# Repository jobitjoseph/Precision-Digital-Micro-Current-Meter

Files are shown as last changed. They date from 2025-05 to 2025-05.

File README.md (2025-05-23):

# Precision-Digital-Micro-Current-Meter
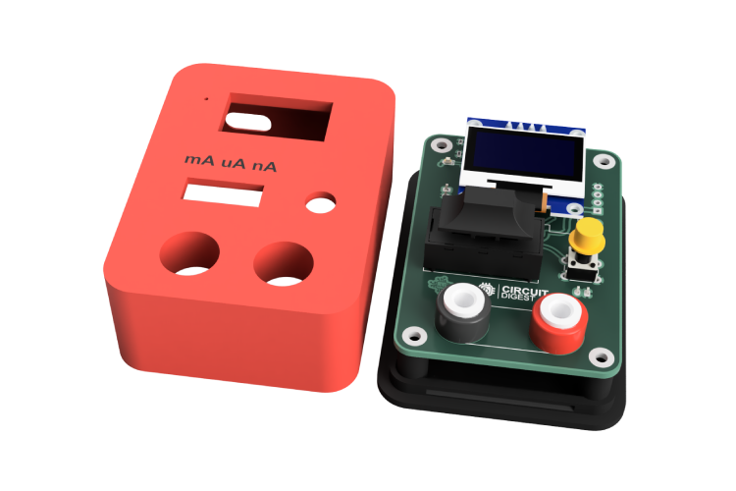
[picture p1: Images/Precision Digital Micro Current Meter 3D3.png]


Keeping track of extremely low current levels is often essential when developing or testing low-power devices, especially in the field of embedded systems and battery-operated electronics. This project presents a compact and reliable micro current meter that makes such measurements straightforward and accessible. It is built around an STM32 microcontroller and features an OLED display for real-time readouts. The analog front end is designed to detect small current flows accurately, converting them into voltage levels that the microcontroller can process with high resolution. Whether you're measuring sleep current in a sensor node or characterising a power-efficient circuit, the device offers a clear and immediate view of power consumption trends.

The meter is designed for ease of use on the workbench, with a focus on readability, stability, and portability. The OLED display provides a crisp output that remains visible under most lighting conditions, while the microcontroller handles signal processing and automatic range detection. Calibration routines ensure measurement consistency across various load conditions. With no need for external tools or complex setups, the device offers a plug-and-play experience for engineers, developers, or hobbyists working with ultra-low power electronics. Its practical design makes it a useful tool for anyone seeking to analyse power usage with precision and simplicity.

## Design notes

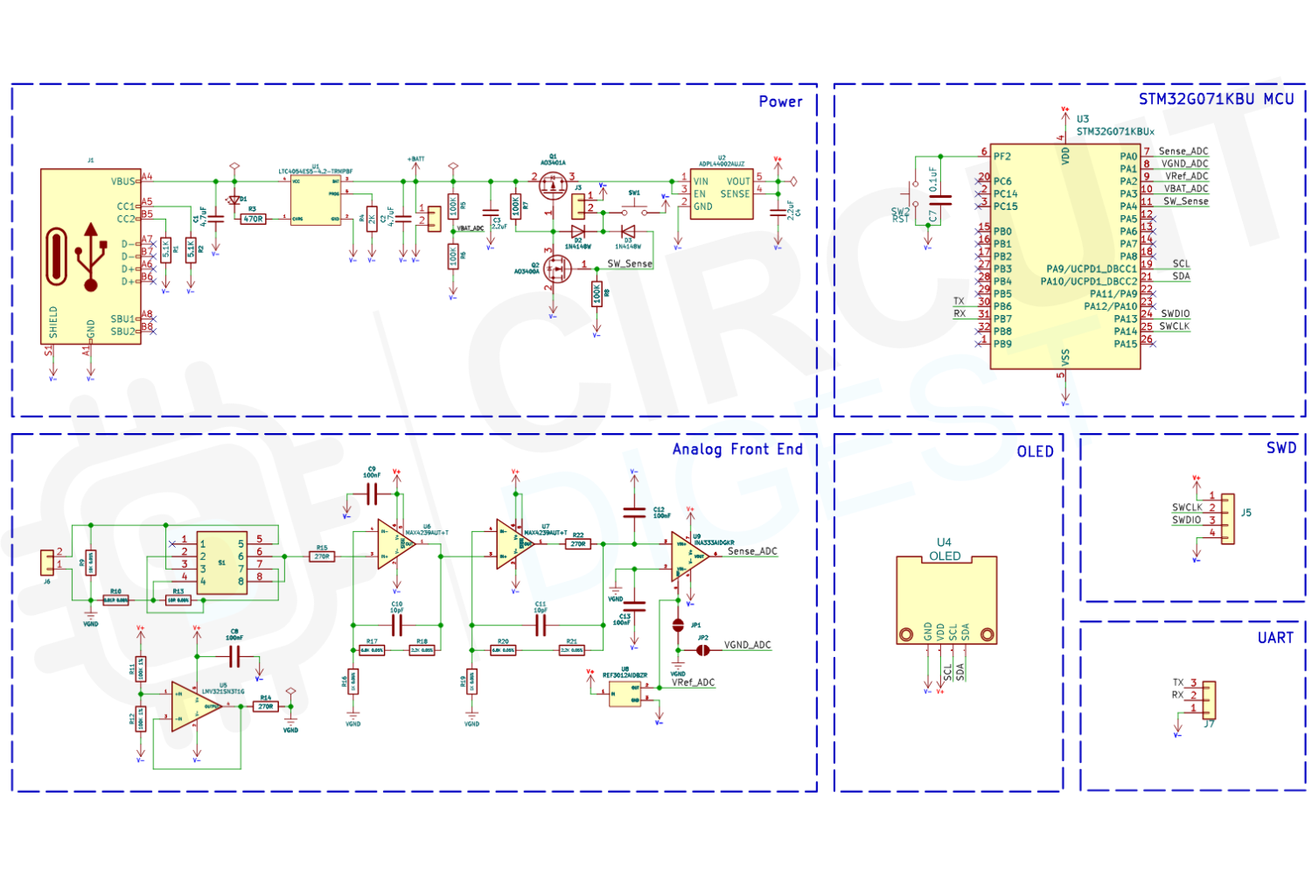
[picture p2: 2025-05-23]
Images/Precision Digital Micro Current Meter Schematics.png

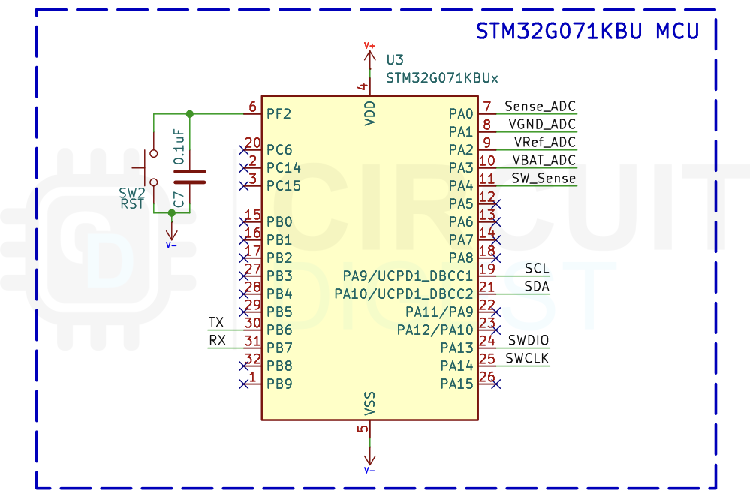
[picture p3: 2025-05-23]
Images/Precision Digital Micro Current Meter MCU.png

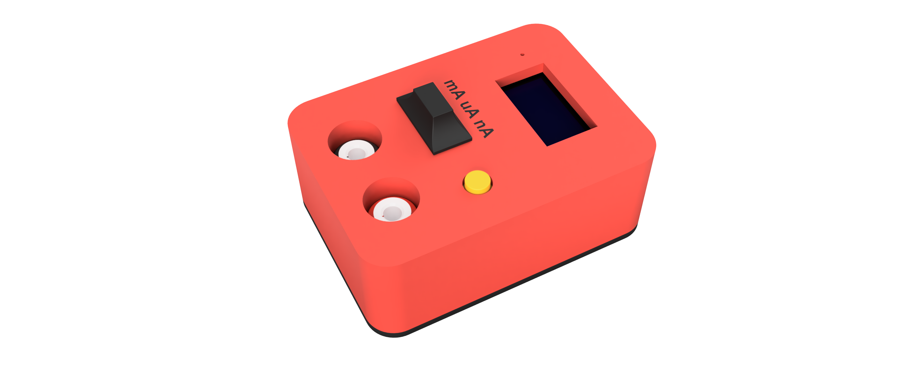
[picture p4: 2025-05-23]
Images/Og/Precision Digital Micro Current Meter 3D view.png

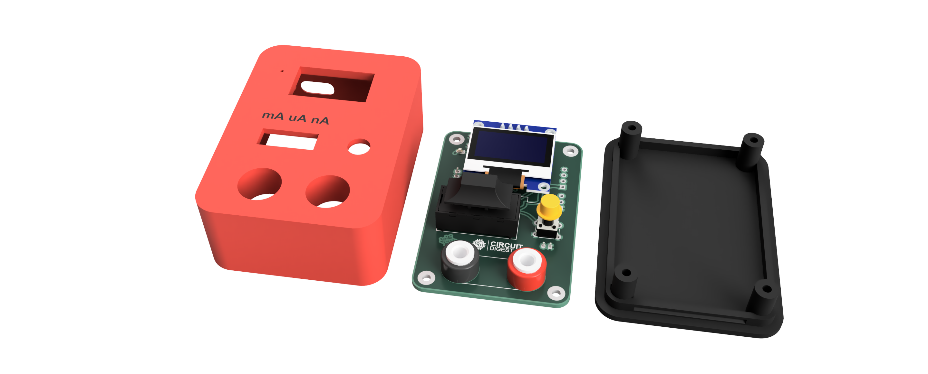
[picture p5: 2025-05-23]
Images/Og/Precision Digital Micro Current Meter 3D.png

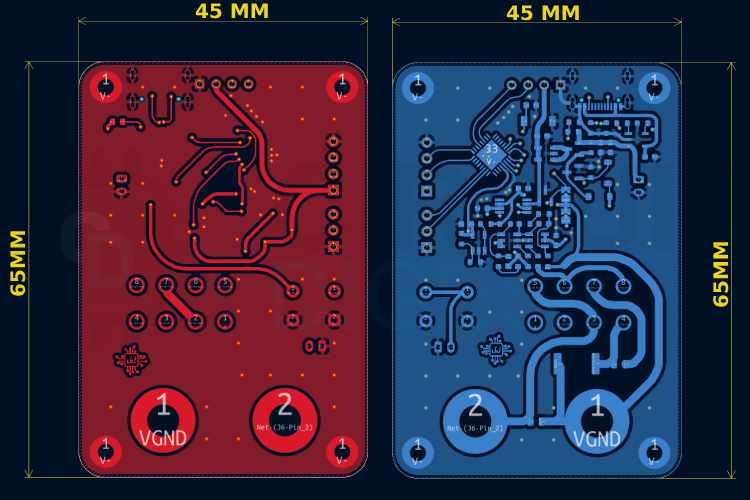
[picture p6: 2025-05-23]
Images/Precision Digital Micro Current Meter PCB Layers.png

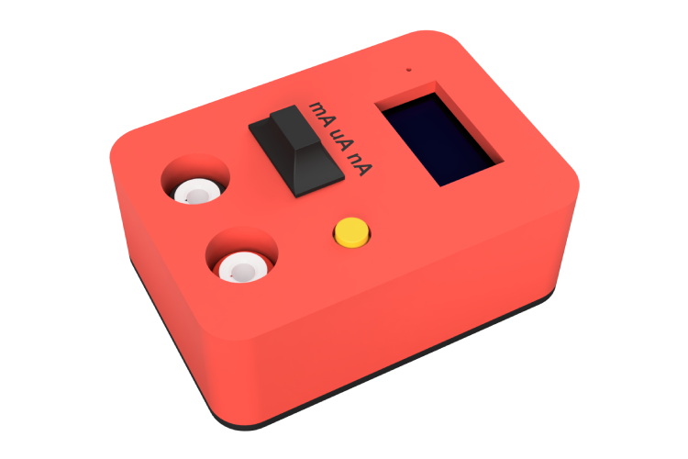
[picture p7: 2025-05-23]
Images/Precision Digital Micro Current Meter 3D1.png

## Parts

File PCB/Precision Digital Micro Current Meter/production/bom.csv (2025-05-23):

Designator | Footprint | Quantity | Value | LCSC Part #
C1, C2 | 0603 | 2 | 4.7uF
C10, C11 | 0603 | 2 | 10pF
C12, C13, C8, C9 | 0603 | 4 | 100nF
C3, C4 | 0603 | 2 | 2.2uF
C7 | 0603 | 1 | 0.1uF
D1 | 0603 | 1 | LED_Small
D2, D3 | D_SOD-123 | 2 | 1N4148W
J1 | USB_C_Receptacle_Palconn_UTC16-G | 1 | USB_C_Receptacle_USB2.0_16P
J2 | JST_PH_B2B-PH-K_1x02_P2.00mm_Vertical | 1 | B2B-PH-SM4-TB(LF)(SN)
J3 | JST_PH_B2B-PH-K_1x02_P2.00mm_Vertical | 1 | Conn_01x02
J4 | PinHeader_1x03_P2.54mm_Vertical | 1 | Conn_01x03
J5 | PinHeader_1x04_P2.54mm_Vertical | 1 | Conn_01x04
J6 | Banana_Jack_2Pin | 1 | Conn_01x02
JP1, JP2 | SolderJumper-2_P1.3mm_Open_TrianglePad1.0x1.5mm | 2 | SolderJumper_2_Open
Q1 | SOT-23 | 1 | AO3401A
Q2 | SOT-23 | 1 | AO3400A
R1, R2 | 0603 | 2 | 5.1K
R10 | 2512 | 1 | 0.01R 0.05%
R11, R12 | 0603 | 2 | 100K 1%
R13 | 0805 | 1 | 10R 0.05%
R14, R15, R22 | 0603 | 3 | 270R
R16, R19 | 0603 | 2 | 1K 0.05%
R17, R20 | 0603 | 2 | 6.8K 0.05%
R18, R21 | 0603 | 2 | 2.2K 0.05%
R3 | 0603 | 1 | 470R
R4 | 0603 | 1 | 2K
R5, R6, R7, R8 | 0603 | 4 | 100K
R9 | 0805 | 1 | 10K 0.05%
S1 | L203111MS02Q | 1 | L203011MS02Q
SW1 | SW_PUSH_6mm | 1 | SW_Push
SW2 | Tactile 3x4x2mm TS-A010 | 1 | RST
U1 | S_5_ADI | 1 | LTC4054ES5-4.2-TRMPBF
U2 | SOT95P280X100-5N | 1 | ADPL44002AUJZ
U3 | QFN-32-1EP_5x5mm_P0.5mm_EP3.45x3.45mm | 1 | STM32G071KBUx
U4 | MODULE_DM-OLED096-636 | 1 | OLED
U5 | SOT95P275X110-5N | 1 | LMV321SN3T1G
U6, U7 | SOT95P280X145-6N | 2 | MAX4239AUT+T
U8 | DBZ3 | 1 | REF3012AIDBZR
U9 | SOP65P490X110-8N | 1 | INA333AIDGKR

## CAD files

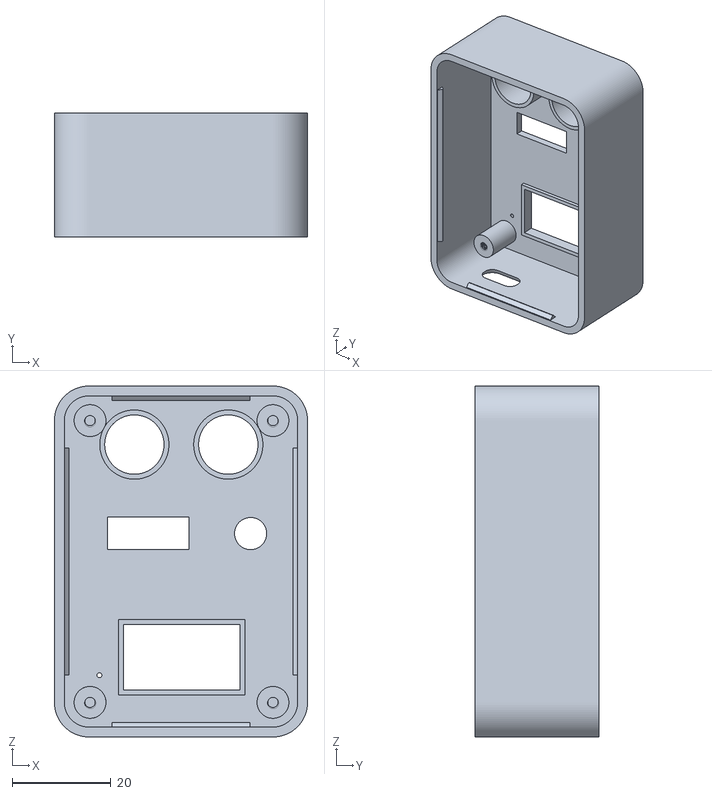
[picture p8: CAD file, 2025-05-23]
3D Files/Top_Case.stl
51.2 x 25.0 x 71.0

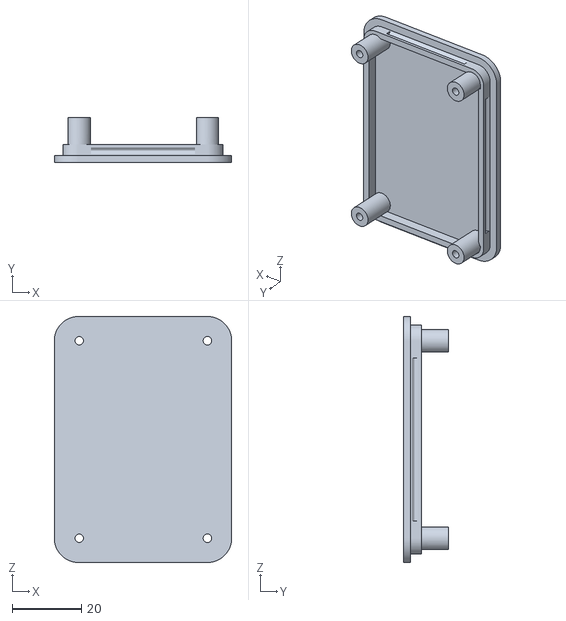
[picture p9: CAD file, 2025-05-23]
3D Files/Bottom_Case.stl
51.2 x 13.0 x 71.0

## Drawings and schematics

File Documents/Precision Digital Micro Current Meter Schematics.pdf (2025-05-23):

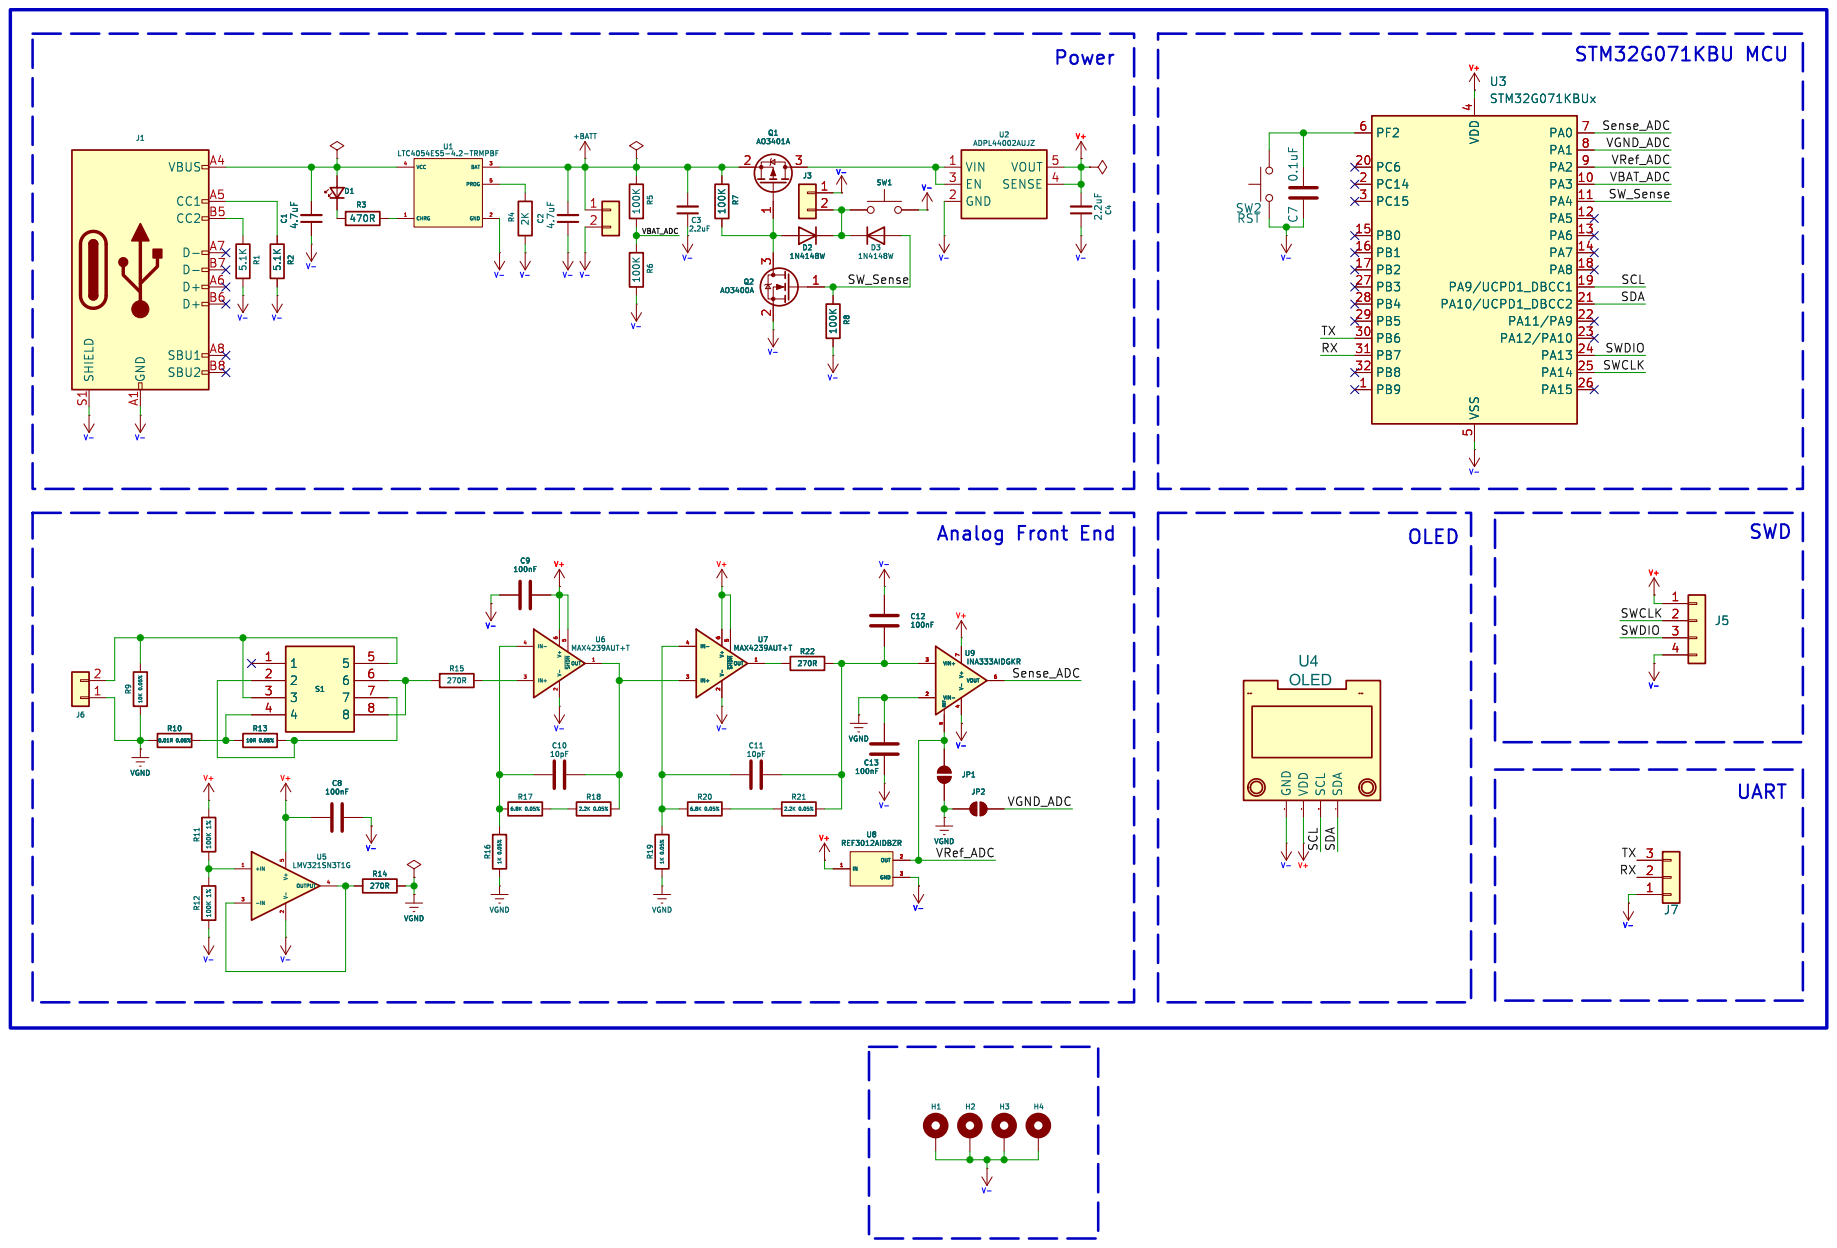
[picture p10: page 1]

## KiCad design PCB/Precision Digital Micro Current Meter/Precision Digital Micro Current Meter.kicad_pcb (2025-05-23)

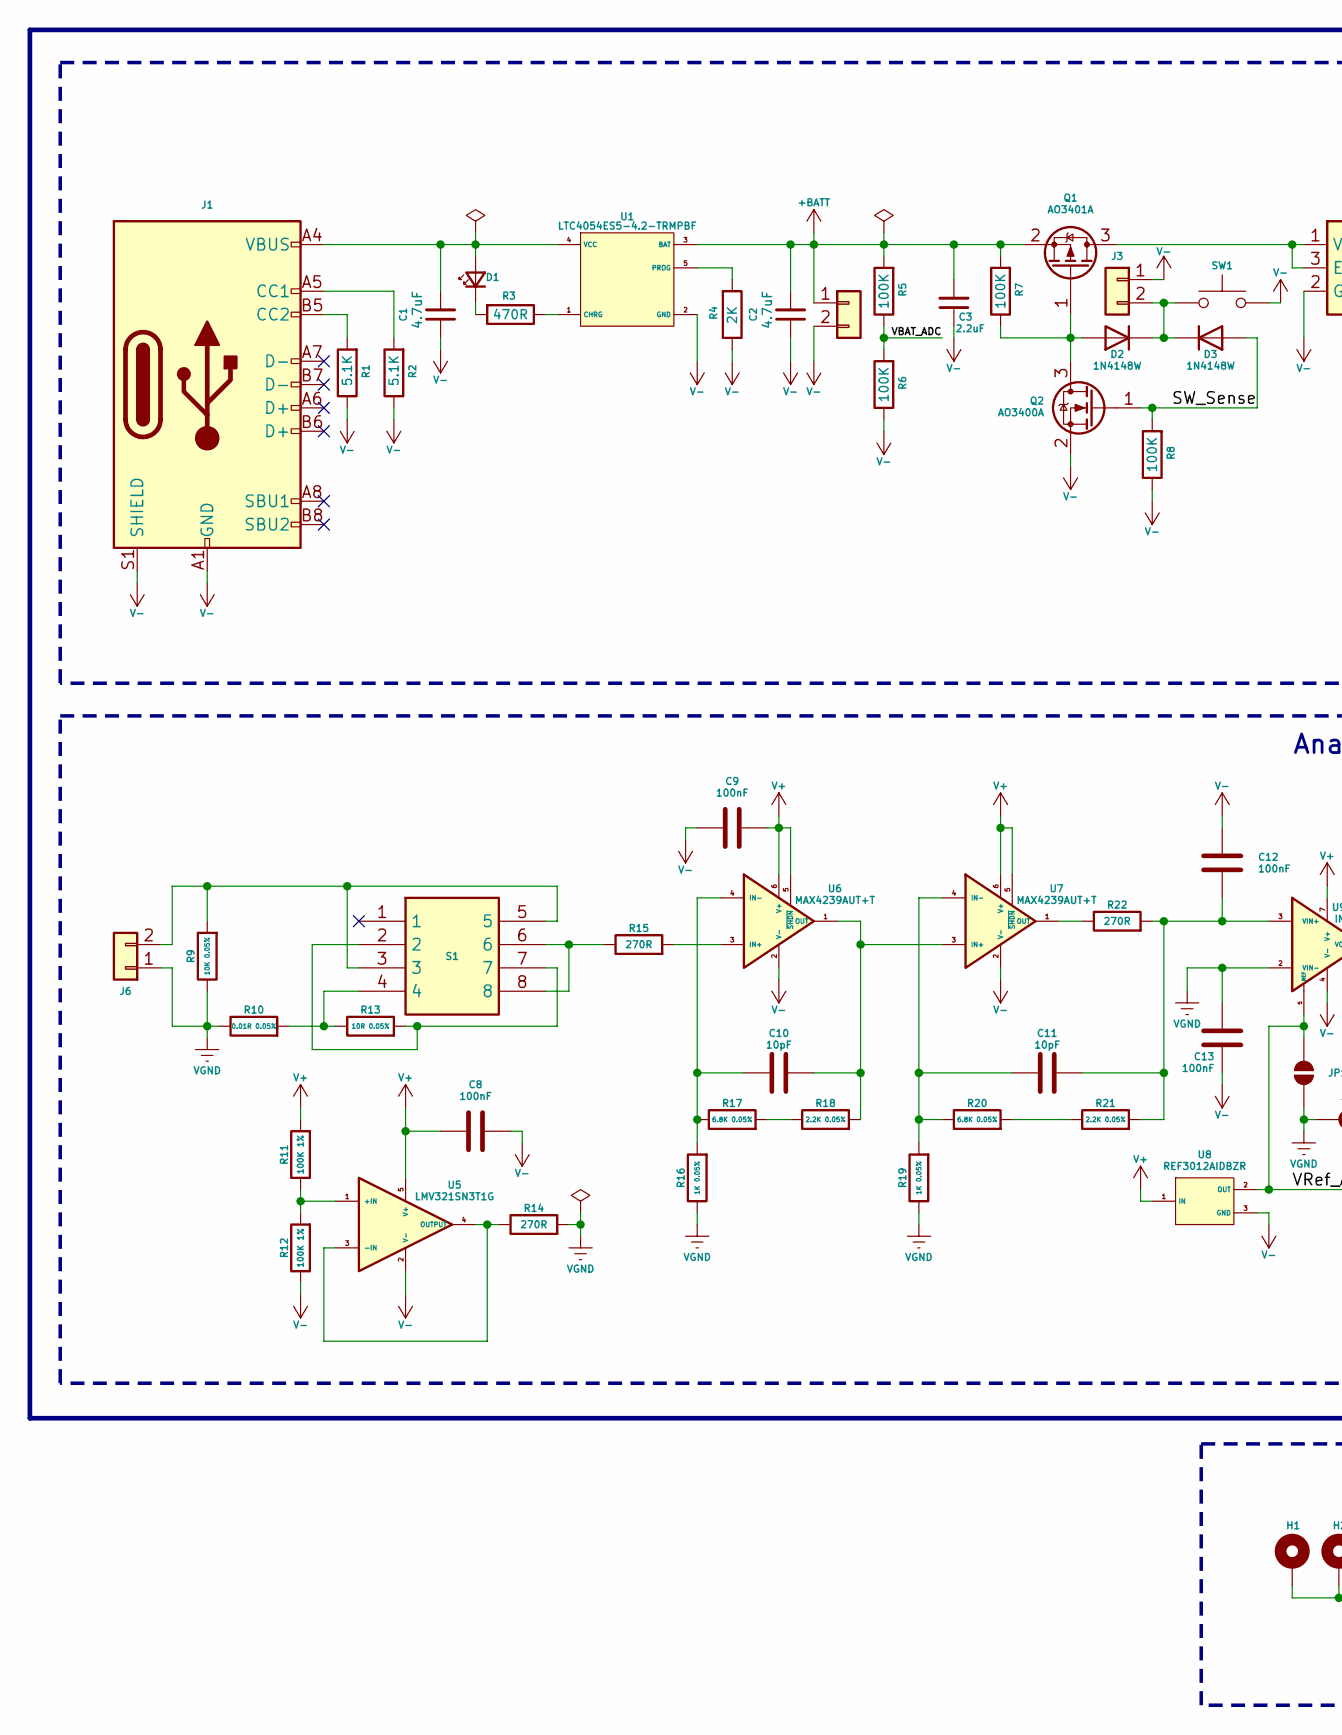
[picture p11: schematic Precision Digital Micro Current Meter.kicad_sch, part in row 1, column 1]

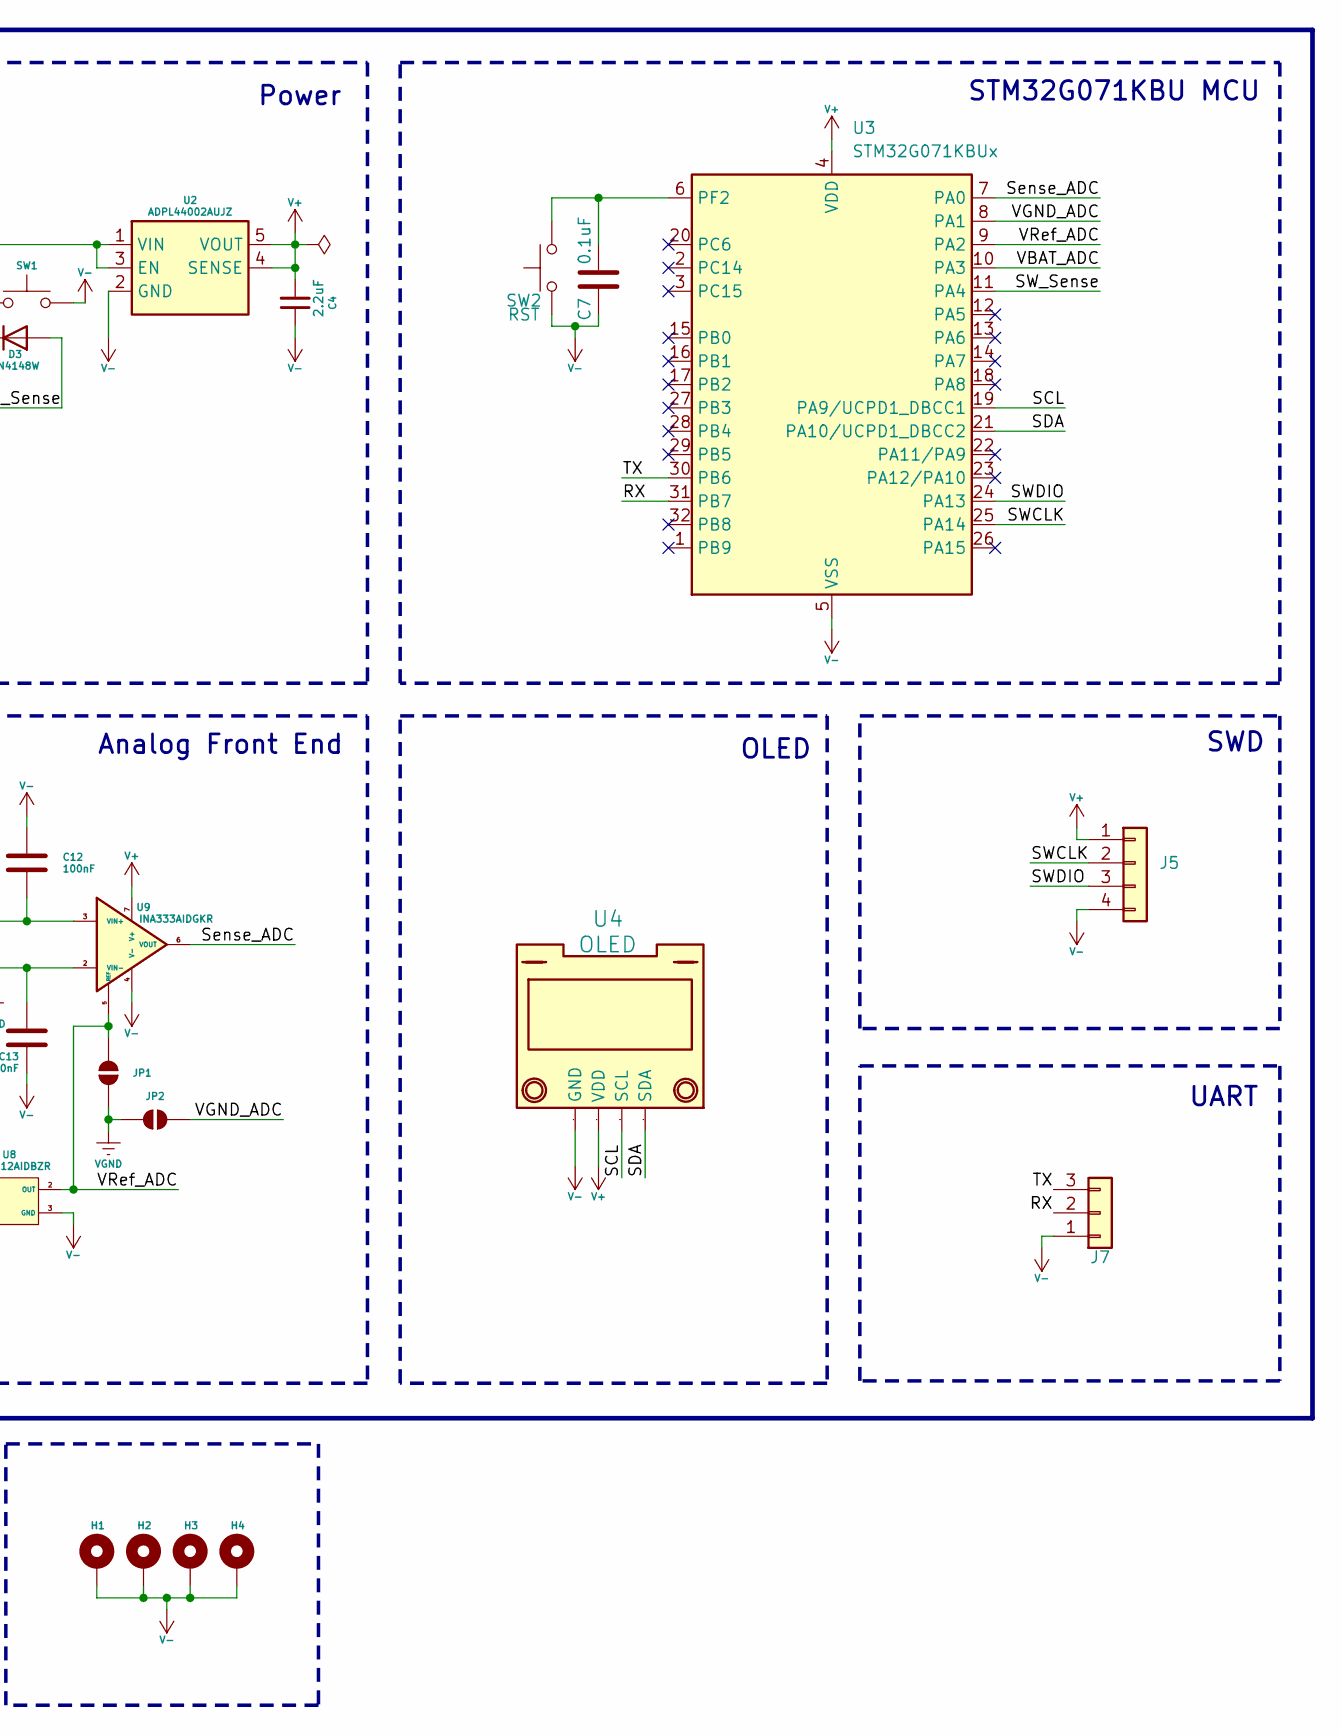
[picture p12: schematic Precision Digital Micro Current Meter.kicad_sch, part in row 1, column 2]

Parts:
C1, C2: 4.7uF; C_0603_1608Metric
C3, C4: 2.2uF; C_0603_1608Metric
C7: 0.1uF; C_0603_1608Metric
C8, C9, C12, C13: 100nF; C_0603_1608Metric
C10, C11: 10pF; C_0603_1608Metric
D1: LED_Small; LED_0603_1608Metric
D2, D3: 1N4148W; D_SOD-123
H1, H2, H3, H4: MountingHole_Pad; MountingHole_2.5mm_Pad
J1: USB_C_Receptacle_USB2.0_16P; USB_C_Receptacle_Palconn_UTC16-G
J2: B2B-PH-SM4-TB(LF)(SN); JST_PH_B2B-PH-K_1x02_P2.00mm_Vertical; DigiKey Part Number 455-1704-ND
J3: Conn_01x02; JST_PH_B2B-PH-K_1x02_P2.00mm_Vertical
J5: Conn_01x04; PinHeader_1x04_P2.54mm_Vertical
J6: Conn_01x02; Banana_Jack_2Pin
J7: Conn_01x03; PinHeader_1x03_P2.54mm_Vertical
JP1, JP2: SolderJumper_2_Open; SolderJumper-2_P1.3mm_Open_TrianglePad1.0x1.5mm
Q1: AO3401A; SOT-23
Q2: AO3400A; SOT-23
R1, R2: 5.1K; R_0603_1608Metric
R3: 470R; R_0603_1608Metric
R4: 2K; R_0603_1608Metric
R5, R6, R7, R8: 100K; R_0603_1608Metric
R9: 10K 0.05%; R_0805_2012Metric
R10: 0.01R 0.05%; R_2512_6332Metric
R11, R12: 100K 1%; R_0603_1608Metric
R13: 10R 0.05%; R_0805_2012Metric
R14, R15, R22: 270R; R_0603_1608Metric
R16, R19: 1K 0.05%; R_0603_1608Metric
R17, R20: 6.8K 0.05%; R_0603_1608Metric
R18, R21: 2.2K 0.05%; R_0603_1608Metric
S1: L203011MS02Q; L203111MS02Q; Mouser Part Number 611-L203011MS02Q
SW1: SW_Push; SW_PUSH_6mm
SW2: RST; Tactile 3x4x2mm TS-A010
U1: LTC4054ES5-4.2-TRMPBF; S_5_ADI
U2: ADPL44002AUJZ; SOT95P280X100-5N; Manufacturer_Part_Number ADPL44002AUJZ2.5-R7
U3: STM32G071KBUx; QFN-32-1EP_5x5mm_P0.5mm_EP3.45x3.45mm
U4: OLED; MODULE_DM-OLED096-636
U5: LMV321SN3T1G; SOT95P275X110-5N; Mouser Part Number 863-LMV321SN3T1G
U6, U7: MAX4239AUT+T; SOT95P280X145-6N; Mouser Part Number 700-MAX4239AUT+T
U8: REF3012AIDBZR; DBZ3
U9: INA333AIDGKR; SOP65P490X110-8N

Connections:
+BATT: C2.2, C3.2, J2.1, Q1.2 (S), R5.2, R7.2, U1.3 (BAT)
/RX: J7.2, U3.31 (PB7); also elsewhere on the board
/SCL: U3.19 (PA9/UCPD1_DBCC1), U4.3 (SCL)
/SDA: U3.21 (PA10/UCPD1_DBCC2), U4.4 (SDA)
/SWCLK: J5.2, U3.25 (PA14)
/SWDIO: J5.3, U3.24 (PA13)
/SW_Sense: D3.2 (A), Q2.1 (G), R8.2, U3.11 (PA4)
/Sense_ADC: U3.7 (PA0), U9.6 (VOUT)
/TX: J7.3, U3.30 (PB6); also elsewhere on the board
/VBAT_ADC: R5.1, R6.2, U3.10 (PA3)
/VGND_ADC: JP2.1 (A), U3.8 (PA1)
/VRef_ADC: JP1.2 (B), U3.9 (PA2), U8.2 (OUT), U9.5 (REF)
unnamed: C1.2, D1.2 (A), J1.A4 (VBUS), J1.A9 (VBUS), J1.B4 (VBUS), J1.B9 (VBUS), U1.4 (VCC)
unnamed: D1.1 (K), R3.2
unnamed: D2.2 (A), Q1.1 (G), Q2.3 (D), R7.1
unnamed: D2.1 (K), D3.1 (K), J3.2, SW1.1
unnamed: J1.A5 (CC1), R2.2
unnamed: J1.B5 (CC2), R1.2
unnamed: J6.2, R9.2, S1.3, S1.5
unnamed: Q1.3 (D), U2.1 (VIN), U2.3 (EN)
unnamed: R10.2, R13.1, S1.4
unnamed: R13.2, S1.2, S1.7
unnamed: R15.1, S1.6, S1.8
unnamed: R17.2, R18.1
unnamed: R20.2, R21.1
unnamed: R3.1, U1.1 (CHRG)
unnamed: R4.2, U1.5 (PROG)
unnamed: C7.2, SW2.2, U3.6 (PF2)
unnamed: R11.1, R12.2, U5.1 (+IN)
unnamed: R14.1, U5.3 (-IN), U5.4 (OUTPUT)
unnamed: R15.2, U6.3 (IN+)
unnamed: C10.1, R16.2, R17.1, U6.4 (IN-)
unnamed: C10.2, R18.2, U6.1 (OUT), U7.3 (IN+)
unnamed: C11.1, R19.2, R20.1, U7.4 (IN-)
unnamed: R22.1, U7.1 (OUT)
unnamed: C11.2, C12.1, R21.2, R22.2, U9.3 (VIN+)
V+: C4.2, C8.1, C9.2, J5.1, R11.2, U2.4 (SENSE), U2.5 (VOUT), U3.4 (VDD), U4.2 (VDD), U5.5 (V+), U6.5 (~SHDN), U6.6 (V+), U7.5 (~SHDN), U7.6 (V+), U8.1 (IN), U9.7 (V+)
V-: C1.1, C2.1, C3.1, C4.1, C7.1, C8.2, C9.1, C12.2, C13.1, H1.1, H2.1, H3.1, H4.1, J1.A1 (GND), J1.A12 (GND), J1.B1 (GND), J1.B12 (GND), J1.S1 (SHIELD), J2.2, J3.1, J5.4, J7.1, Q2.2 (S), R1.1, R2.1, R4.1, R6.1, R8.1, R12.1, SW1.2, SW2.1, U1.2 (GND), U2.2 (GND), U3.5 (VSS), U3.33 (VSS), U4.1 (GND), U5.2 (V-), U6.2 (V-), U7.2 (V-), U8.3 (GND), U9.4 (V-); also elsewhere on the board
VGND: C13.2, J6.1, JP1.1 (A), JP2.2 (B), R9.1, R10.1, R14.2, R16.1, R19.1, U9.2 (VIN-)

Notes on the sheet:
Power
STM32G071KBU MCU
OLED
UART
SWD
Analog Front End

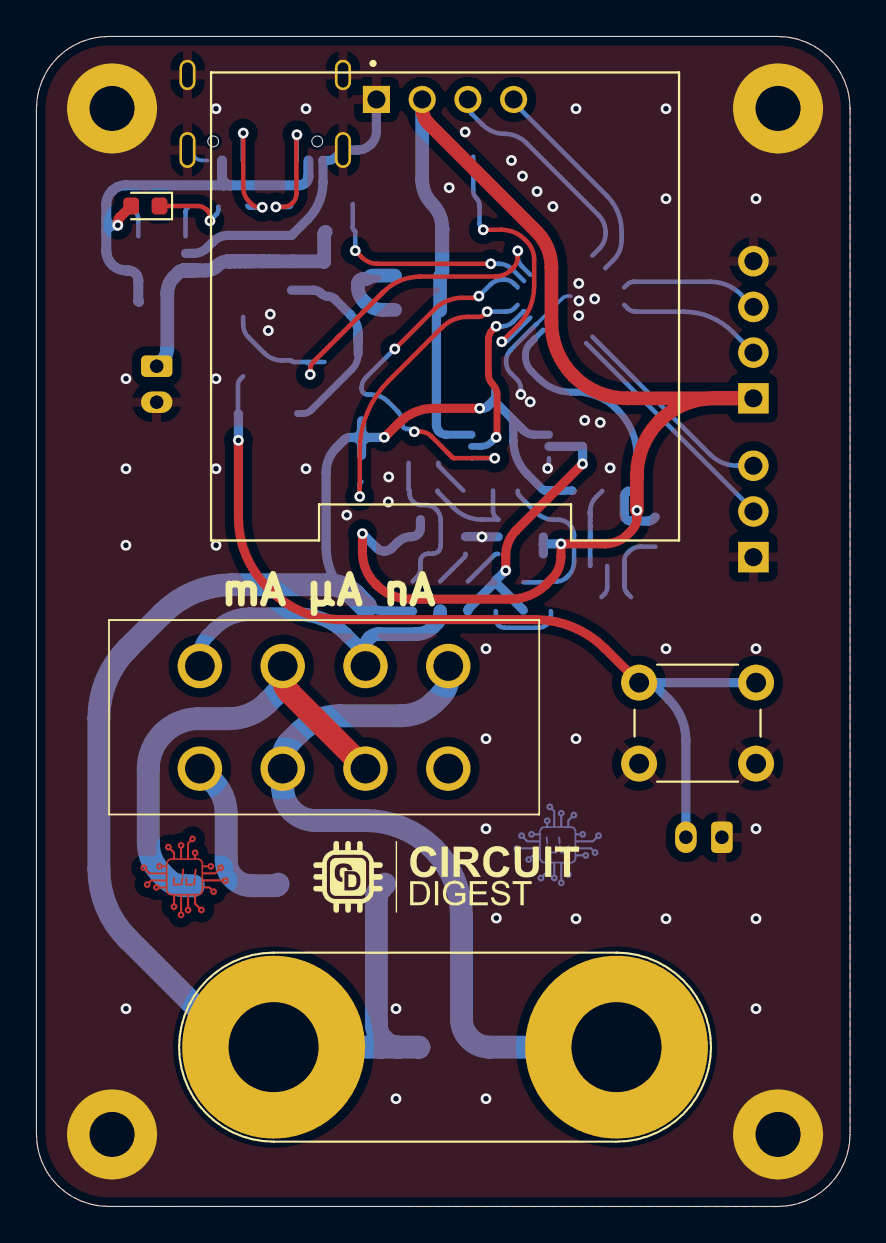
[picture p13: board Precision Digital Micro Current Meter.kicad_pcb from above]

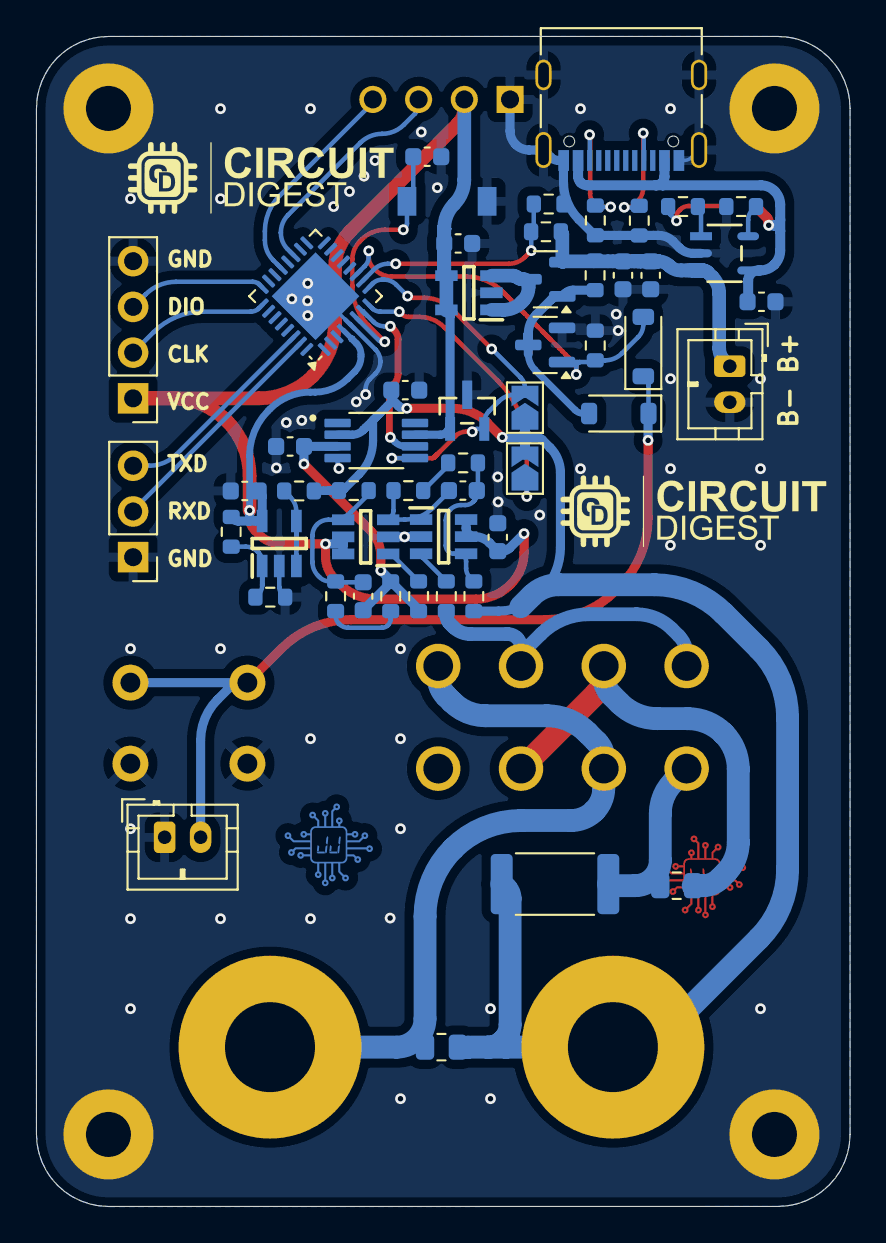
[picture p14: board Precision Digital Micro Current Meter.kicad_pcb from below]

Board: 2 copper layers, 45.2 x 65.0 mm, 62 parts (53 on the bottom side), 39 nets.

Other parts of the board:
J4: Conn_01x03; PinHeader_1x03_P2.54mm_Vertical

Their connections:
/RX: J4.2; also elsewhere on the board
/TX: J4.3; also elsewhere on the board
V-: J4.1; also elsewhere on the board

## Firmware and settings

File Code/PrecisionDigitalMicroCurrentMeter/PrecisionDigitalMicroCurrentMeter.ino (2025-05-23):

/*
 * Project Name: Precision Digital Micro Current Meter
 * Project Brief: Precision Digital Micro Current Meter based STM32G071KBU MCU.
 * Author: Jobit Joseph @ https://github.com/jobitjoseph
 * IDE: Arduino IDE 2.3.6
 * Arduino Core: ESP32 Arduino Core V 3.2.0
 * Dependencies : U8g2 Library V 2.35.30 @ https://github.com/olikraus/u8g2
 *
 * Copyright © Jobit Joseph
 * Copyright © Semicon Media Pvt Ltd
 * Copyright © Circuitdigest.com
 * 
 * This code is licensed under the following conditions:
 *
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
 * 2. Commercial Use:
 * For any commercial use of this software, you must obtain a separate license
 * from the original author. Contact the author for permissions or licensing
 * options before using this software for commercial purposes.
 *
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
 * Author: Jobit Joseph
 * Date: 23 May 2025
 *
 * For commercial use or licensing requests, please contact [jobitjoseph1@gmail.com].
 */

#include <Wire.h>
#include <HardwareSerial.h>
#include <U8g2lib.h>
#define LATCH_PIN PA4
#define NUM_SAMPLES 2
#define SAMPLE_DELAY 10
#define REF_VOLTAGE 1249.3f  // float for precision

// Define our custom HardwareSerial
HardwareSerial MySerial(PB6, PB7);  // TX, RX
U8G2_SSD1306_128X64_NONAME_F_HW_I2C u8g2(U8G2_R0, /* reset=*/U8X8_PIN_NONE);
volatile bool buttonPressed = false;
volatile bool buttonReleased = false;
volatile unsigned long lastInterruptTime = 0;
unsigned long releaseTime = 0;
const unsigned long debounceDelay = 50;
const unsigned long shutdownDelay = 1000;

unsigned long lastBatteryUpdate = 0;
float batteryVoltage = 0;
int AmpV = 0;
float AmpVF = 0;
int batteryPercent = 0;

void buttonISR() {
  unsigned long now = millis();
  if (now - lastInterruptTime < debounceDelay) return;

  if (digitalRead(LATCH_PIN) == LOW) {
    buttonPressed = true;
    buttonReleased = false;
  } else {
    if (buttonPressed) {
      buttonReleased = true;
      releaseTime = now;
      delay(500);
      pinMode(LATCH_PIN, OUTPUT);
      digitalWrite(LATCH_PIN, LOW);
      while (1)
        ;
    }
    buttonPressed = false;
  }
  lastInterruptTime = now;
}

void setup() {
  pinMode(LATCH_PIN, INPUT_PULLUP);
  attachInterrupt(digitalPinToInterrupt(LATCH_PIN), buttonISR, CHANGE);
  MySerial.begin(115200);
  MySerial.println("STM32G071 ADC with External Reference (PA2)");
  analogReadResolution(12);
  u8g2.begin();
}

void loop() {
  unsigned long now = millis();
  if (now - lastBatteryUpdate > 500) {
    float vdda = measureVDDA();
    batteryVoltage = measureInputVoltage(PA3, vdda) * 2.0f;
    float Vref = measureInputVoltage(PA1, vdda);
    float ampVoltage = measureInputVoltage(PA0, vdda);
    //AmpV = ((int)((ampVoltage - Vref) / 2.0f)) - 3;
    //float error_percent = 4.77f;
    //AmpV = (int)(((ampVoltage - Vref) / 2.0f) * (1.0f - error_percent / 100.0f))-3;
    float raw = ((ampVoltage - Vref) / 1.0f);
    float offset = 6.0f;
    float error_percent = 0.0f;
    //AmpV = (int)((raw - offset) * (1.0f - error_percent / 100.0f));
    AmpVF = (raw  * (1.0f - error_percent / 100.0f)- offset);
    AmpV = (int)AmpVF;
    batteryPercent = batteryLevelPercent((int)batteryVoltage);

    MySerial.print("VDDA: "); MySerial.print(vdda);
    MySerial.print(" mV, Vref: "); MySerial.print(Vref);
    MySerial.print(" mV, PA2: "); MySerial.print(measureInputVoltage(PA2, vdda));
    MySerial.print(" mV, Amp: "); MySerial.println(AmpV);

    lastBatteryUpdate = now;

    u8g2.clearBuffer();
    u8g2.setFont(u8g2_font_5x8_tr);

    int iconX = 96, iconY = 0, iconW = 28, iconH = 12;
    char batteryPercentStr[6];
    itoa(batteryPercent, batteryPercentStr, 10);
    strcat(batteryPercentStr, "%");
    u8g2.drawStr(iconX - 20, iconY + 10, batteryPercentStr);

    drawBatteryIconWithBars(iconX, iconY, iconW, iconH, batteryPercent);

    char AmpStr[7];
    if (AmpV < 0) {
      sprintf(AmpStr, "-%04d", abs(AmpV));
    } else {
      sprintf(AmpStr, " %04d", AmpV);
    }

    u8g2.setFont(u8g2_font_inb33_mn);
    u8g2.drawStr(-10, 62, AmpStr);
    u8g2.sendBuffer();
  }
}

float measureVDDA() {

  uint32_t sum = 0;
  for (int i = 0; i < NUM_SAMPLES; i++) {
    sum += oversampledADC(PA1);
    delayMicroseconds(SAMPLE_DELAY);
  }
  float adcAvg = (float)sum / NUM_SAMPLES;
  float vdda = (REF_VOLTAGE * 65535.0f) / adcAvg;
  return vdda;
}

float measureInputVoltage(uint32_t pin, float vdda) {
  uint32_t sum = 0;
  for (int i = 0; i < NUM_SAMPLES; i++) {
    sum += oversampledADC(pin);  
    delayMicroseconds(SAMPLE_DELAY);
  }
  float adcAvg = (float)sum / NUM_SAMPLES;
  float voltage = (adcAvg * vdda) / 65535.0f;
  return voltage;
}

uint32_t oversampledADC(uint32_t pin) {
  uint32_t sum = 0;
  const int oversample_count = 256;  // 2^(2 × (16 - 12)) = 256

  for (int i = 0; i < oversample_count; i++) {
    sum += analogRead(pin);  // 12-bit reading
    delayMicroseconds(SAMPLE_DELAY);   // optional: allow settling
  }

  // Average and scale to 16-bit range
  uint32_t avg = sum / oversample_count;
  uint32_t adc16 = avg << 4;  // 12-bit to 16-bit shift (multiply by 16)
  // Ignore 3 LSBs
  const int ignore_lsb = 4;
  adc16 = (adc16 >> ignore_lsb) << ignore_lsb;

  return adc16;
}

int batteryLevelPercent(int v_bat) {
  int percent = (v_bat - 3000) * 100 / (4200 - 3000);
  if (percent > 100) percent = 100;
  if (percent < 0) percent = 0;
  return percent;
}

void drawBatteryIconWithBars(int x, int y, int w, int h, int percent) {
  u8g2.drawFrame(x, y, w, h);
  u8g2.drawBox(x + w, y + h / 3, 2, h / 3);

  int numBars = 4;
  int barSpacing = 2;
  int barWidth = (w - 6 - (numBars - 1) * barSpacing) / numBars;
  int barHeight = h - 4;
  int barsToDraw = (percent + 24) / 25;

  for (int i = 0; i < barsToDraw; i++) {
    int bx = x + 2 + i * (barWidth + barSpacing);
    u8g2.drawBox(bx, y + 2, barWidth, barHeight);
  }
}
